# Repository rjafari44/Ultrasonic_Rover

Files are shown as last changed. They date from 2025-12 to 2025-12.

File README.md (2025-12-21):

# Ultrasonic Rover

#### This project utilizes an ultrasonic sensor, servo motor, and an Arduino Nano microcontroller to create an obstacle-avoiding rover called **Cornelius**. Included are STL files for 3D printing, an LTspice schematic for wiring visualization, images, and a parts list. The project is divided into Mechanical, Electrical, and Programming sections for clarity. Although not a direct contributor, **Kaveh Zare** played an important role in refreshing my C++ skills, which helped make this project possible. Check out his GitHub here: [github.com/kavehzare98](https://github.com/kavehzare98)

--- 

### Image of Rover:
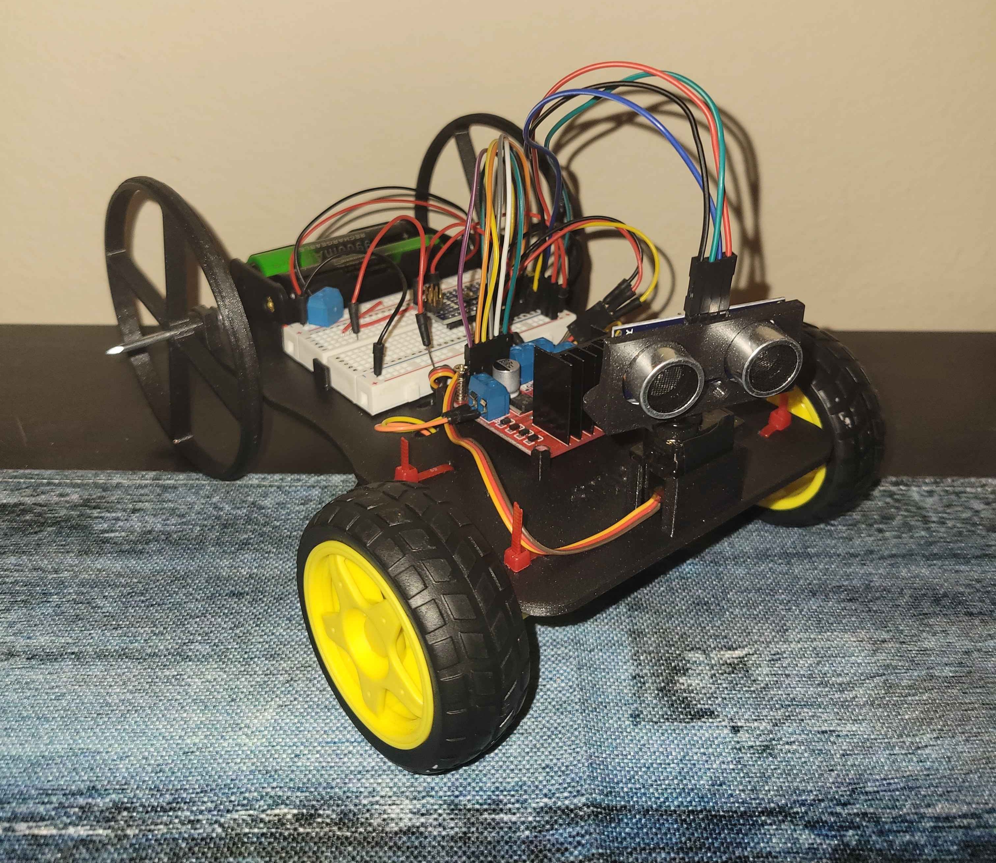
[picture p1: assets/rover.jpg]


---

### Parts List:

- Arduino Nano
- HC-SR04 ultrasonic distance sensor
- 2× TT DC gear motors
- 2x TT motor wheels
- Two port screw terminal
- L298N motor driver
- Micro servo (MG90 used; SG90 recommended)
- 2× 18650 Li-ion batteries (with holder)
- 470 µF 16 V electrolytic capacitor
- Breadboard
- Dupont jumper wires
- 3D-printed chassis and wheels (PLA)
- Zipties
- Screws, washers, nails (for wheel mounting)
- Electrical tape (for servo fitment)

---

### Mechanical:
The chassis is custom-designed, and the wheels are inspired by a design from Prof. Wolken at Irvine Valley College. The ultrasonic sensor bracket is not included in this repository. I recommend sourcing or designing one that best fits your build. Many suitable brackets can be found online (e.g., searching “HC-SR04 bracket” on Printables).
- **Printing:** Chassis and wheels were 3D printed with PLA.
- **Chassis Features:**
  - Holes for zipties to secure the motors and components
  - Holes for routing TT motor wires to the motor driver
  - Bracket for the servo motor (slightly loose—use tape or a small shim for tightness)
- **Wheels:**
  - Front wheels mounted to motors with zipties
  - Rear wheels attached via two nails through a mounting bracket
- **Component Mounting:** Breadboard, motor driver, and battery holder secured with tabs on the chassis
- **Ultrasonic Sensor:** Custom bracket (found online) reinforced with screws and washers for stability.
- **Servo Motor:** MG90 (metal gears, overkill for this project—an SG90 or similar plastic gear servo works fine)
- **Notes:** Some wheel wobbling may occur, especially during extended operation

#### Assembly on Onshape:

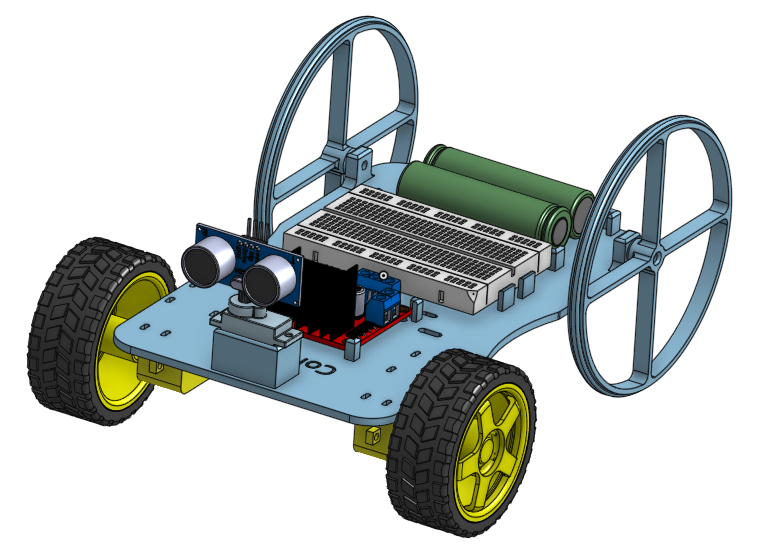
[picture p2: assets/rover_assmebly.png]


*The Onshape assembly shows the rough placement of parts. Components are not fully constrained or mated, so this is meant as a visual reference only. Assembly file is provided.*

---

### Electrical:
The rover is powered by two 18650 LiPo batteries in series (nominal 3.7 V each, 7.4 V total).
- **Voltage Considerations:**
  - Arduino Nano VIN: 7–14 V
  - MG90 servo: up to 12 V
  - Actual battery voltage ~8 V. sufficient for this setup
- **Motors:** TT motors (3–6 V). voltage drop across the motor driver brings them into the safe range
- **Logic Power:**
  - Arduino Nano and L298N motor driver have built-in 5 V regulators
  - 5 V from Nano powers both the HC-SR04 ultrasonic sensor and the MG90 servo
- **Capacitor:** 470 µF across power rail and GND smooths voltage spikes
- **Wiring:** Dupont jumper wires were used. Ensure solid connections to avoid intermittent
failures
- **Current Draw:** Realistically, total current should not exceed 2 A or get close.

#### Circuit Schematic: 

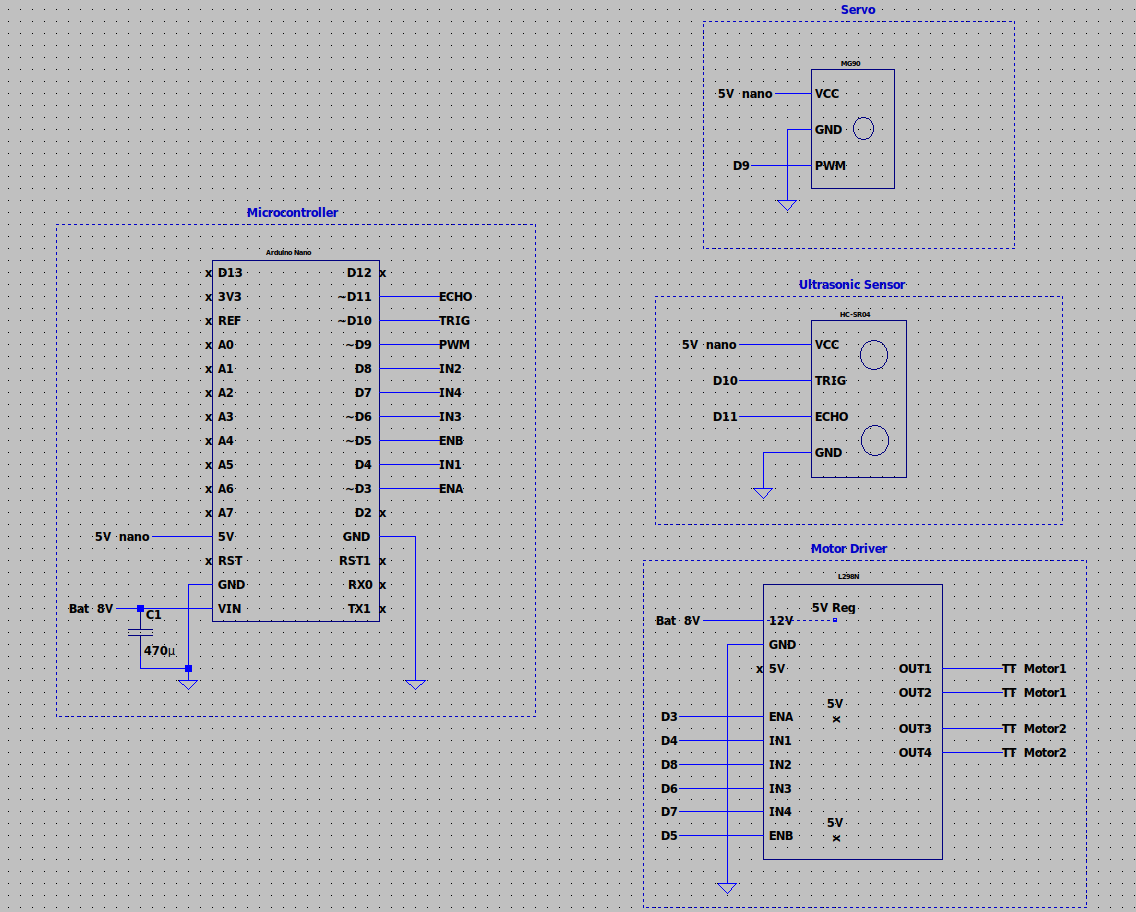
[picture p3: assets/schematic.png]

---

### Programming: 
The code is functional but can be optimized to reduce load on the Nano. It uses multiple `.cpp` files with a header file.
- **Compilation:** Arduino CLI (Linux tested)
- **Arduino IDE:** Should also work, though you may need to include all files manually
- **Shell Script:** Provided (`run.sh`) to simplify execution. Ensure it has executable permissions (`chmod +x run.sh`)

### Movement Logic:

| Movement | IN1 | IN2 | IN3 | IN4 | ENA | ENB |
|---|-----|-----|-----|-----|-----|-----|
| Forward | 1 | 0 | 1 | 0 | PWM | PWM |
| Backward | 0 | 1 | 0 | 1 | PWM | PWM |
| Turn Left  | 0 | 1 | 1 | 0 | PWM | PWM |
| Turn Right | 1 | 0 | 0 | 1 | PWM | PWM |
| Stop | 0 | 0 | 0 | 0 | 0 | 0 |

**0 = Low**\
**1 = High**\
**PWM = 0-255 (analog), LOW or HIGH (digital)**

---

### How to run: 

### 1. Find Connected Serial Port
#### On Linux
```bash
ls /dev/tty*
```   

#### With Arduino CLI (recommended method)
```bash
arduino-cli board list
```

### 2. Run the program in CLI
```bash
./run.sh
```

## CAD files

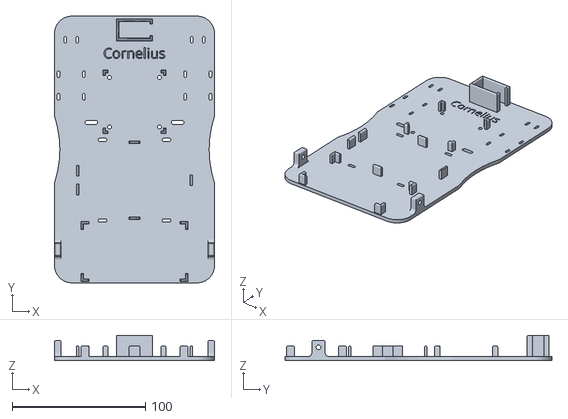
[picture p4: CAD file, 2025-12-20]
cadFiles/Chassis.stl
120.0 x 200.0 x 19.0

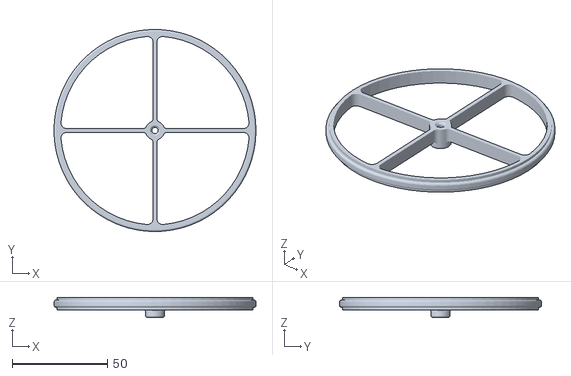
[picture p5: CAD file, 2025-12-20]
cadFiles/Wheel.stl
106.0 x 106.0 x 10.5

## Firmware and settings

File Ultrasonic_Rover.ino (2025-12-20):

#include "myheader.h"

Servo myServo;                            // define servo object
const int servoPin{9};                    // set servo pin
const int obstacleLimit{20};              // set detection limit (20 cm)
unsigned long forwardStartTime{};         // variable to track time since movement
const unsigned long forwardTimeout{3000}; // variable to limit movement after set time

// function for setting up the arduino code, runs once, returns nothing
void setup() {
  // setting the l298n pins as output
  pinMode(ENA, OUTPUT);
  pinMode(ENB, OUTPUT);
  pinMode(IN1, OUTPUT);
  pinMode(IN2, OUTPUT);
  pinMode(IN3, OUTPUT);
  pinMode(IN4, OUTPUT);

  // setup the ultrasonic pins
  pinMode(trigPin, OUTPUT);
  pinMode(echoPin, INPUT);

  // setup the servo 
  myServo.attach(servoPin);
  myServo.write(90); // center
  delay(1000);
}

// function for running the arduino code, loops, returns nothing
void loop() {
  int distance{};               // variable of integer type for distance to an object
  int leftDist{};               // variable of integer type for distance to an object on the left side
  int rightDist{};              // variable of integer type for distance to an object on the right side
  bool obstacleDetected{};      // variable of boolean type for object detected
  bool forwardTimeoutReached{}; // variable of boolean type for forward movement

  distance = getDistance();  // get distance to object

  // if obstacle is detected within detection limit, set true, otherwise false
  obstacleDetected = (distance <= obstacleLimit); 

  // if time since movement is not zero and time elapsed is more than 3 seconds, set true, otherwise false
  forwardTimeoutReached = (forwardStartTime != 0 && millis() - forwardStartTime >= forwardTimeout); // if time since movement is not zero and time elapsed is more than 3 seconds, set true, otherwise false

  // Start forward motion if path is clear and not already moving
  if (distance > obstacleLimit && forwardStartTime == 0) {
    moveForward();
    forwardStartTime = millis();
  }

  // Run obstacle avoidance if either an obstacle is detected or set time has passed
  if (obstacleDetected || forwardTimeoutReached) {
    stopMotors();
    forwardStartTime = 0; // reset timer

    // Back up a bit
    delay(200);
    moveBackward();
    delay(300);
    stopMotors();

    // Look left and right
    leftDist = lookLeft();
    rightDist = lookRight();

    // Decide which way to turn
    if (leftDist > rightDist) {
      turnLeft();
    } else {
        turnRight();
    }

    delay(400);
    stopMotors();
  }
}

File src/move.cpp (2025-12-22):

#include "myheader.h"

/* A chart is provided on the README for how the different Movements are achieved with the TT motors */

const int motorSpeed {150};      // Global variable of integer type for speed (PWN, 0–255)
const float turnMultiplier{0.8}; // Global variable of float type for turning speed multiplier

// function for moving both motors forward, returns nothing
void moveForward() {
  digitalWrite(IN1, HIGH);
  digitalWrite(IN2, LOW);
  digitalWrite(IN3, HIGH);
  digitalWrite(IN4, LOW);
  analogWrite(ENA, motorSpeed);
  analogWrite(ENB, motorSpeed);
}

// function for moving both motors backwards, returns nothing
void moveBackward() {
  digitalWrite(IN1, LOW);
  digitalWrite(IN2, HIGH);
  digitalWrite(IN3, LOW);
  digitalWrite(IN4, HIGH);
  analogWrite(ENA, motorSpeed);
  analogWrite(ENB, motorSpeed);
}

// function for turning left at a set speed, returns nothing
void turnLeft() {
  int turnSpeed{}; // variable of integer type for turn speed

  turnSpeed = motorSpeed * turnMultiplier; // calculate turning speed with the global variables

  digitalWrite(IN1, LOW);
  digitalWrite(IN2, HIGH);
  digitalWrite(IN3, HIGH);
  digitalWrite(IN4, LOW);
  analogWrite(ENA, turnSpeed);
  analogWrite(ENB, turnSpeed);
}

// function for turning right at a set speed, returns nothing
void turnRight() {
  int turnSpeed{}; // variable of integer type for turn speed

  turnSpeed = motorSpeed * turnMultiplier; // calculate turning speed with the global variables

  digitalWrite(IN1, HIGH);
  digitalWrite(IN2, LOW);
  digitalWrite(IN3, LOW);
  digitalWrite(IN4, HIGH);
  analogWrite(ENA, turnSpeed);
  analogWrite(ENB, turnSpeed);
}

// function for stopping motor movement, returns nothing
void stopMotors() {
  analogWrite(ENA, 0);
  analogWrite(ENB, 0);
}

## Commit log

2025-12-20 fixed the distance.cpp for more accurate turn movement
    [Ultrasonic_Rover.ino, distance.cpp, move.cpp]
2025-12-20 Added image, CAD files, and updated README
    [Chassis.stl, Wheel.stl]
2025-12-20 corrected timing on turn
    [distance.cpp]
